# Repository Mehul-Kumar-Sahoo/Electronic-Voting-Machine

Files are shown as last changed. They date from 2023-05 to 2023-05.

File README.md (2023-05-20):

# Electronic Voting Machine (EVM)

Skills: Proteus 7, Digital Electronics

- I am Mehul Kumar Sahoo of in B.Tech Part 2 in IIT (BHU), Varanasi persuing Electronics Engineering. 
- I have made an Electronic Voting Machine (EVM) using PROTEUS for the event of DIGISIM in Udyam'23, annual technical fest of Electronics Engineering Society IIT (BHU), Varanasi.
- I have also designed a PCB using EagleCAD to implement the EVM (Schematic, Board and Gerber files are also attached in this repository).



## Features
 1) A start button to begin the voting process for a voter giving them a window of 15 seconds to vote for a person.
 
 
 
 2) After each voting button is pressed, the circuit stops working for 3 seconds to prevent devouncing of a button.



 3) A count button which when pressed counts the number of votes the winning person has.
 4) 7-segment displays to display the winning candidate, the number of votes for winning candidate, and the time left for voting.
 
 

## PCB Design (Made using EagleCAD)
### Top Layer



### Bottom Layer



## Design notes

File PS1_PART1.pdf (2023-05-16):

# DIGISIM PS-1 PART 1 EXPLANATION

Team Members:
1) Name – Mehul Kumar Sahoo
Email – mehul.kumarsahoo.ece21@itbhu.ac.in
2) Name – Vaibhav Bansal
Email – vaibhav.bansal.ece21@itbhu.ac.in Circuit Diagram:

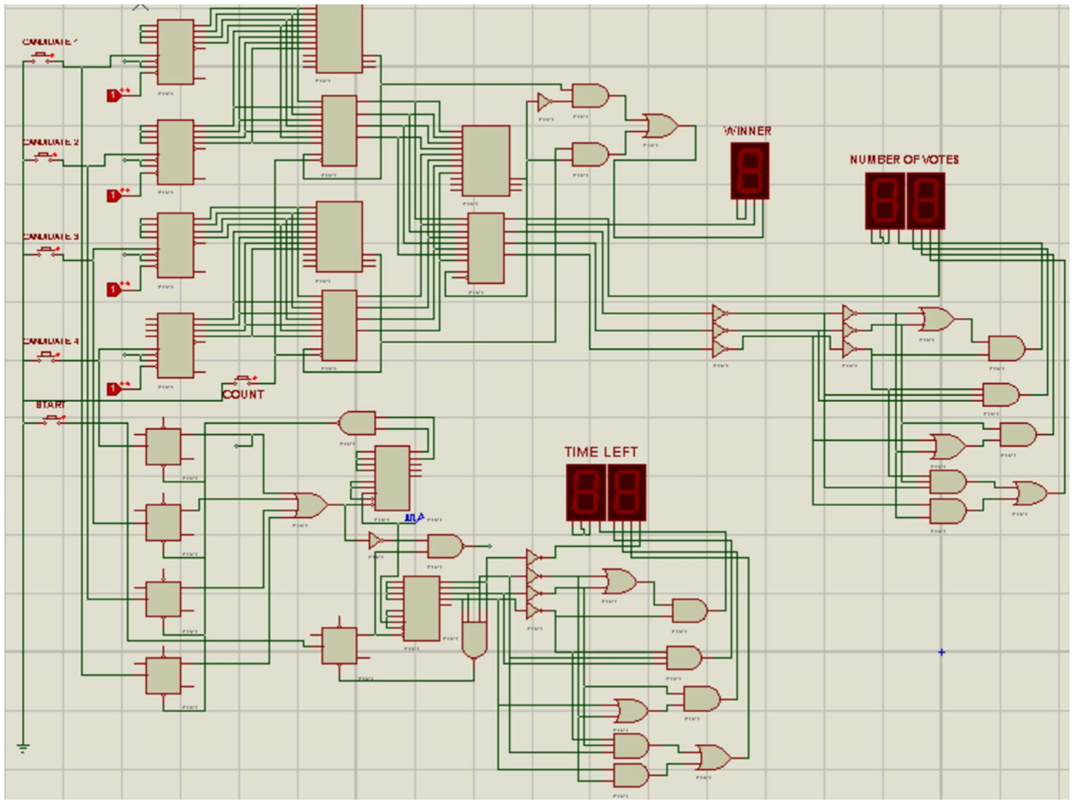
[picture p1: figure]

We have implemented the following features in the Electronic Vong Machine.

### 1. A start buon to begin the vong process gives the voter a window of 15

seconds to vote for a person.

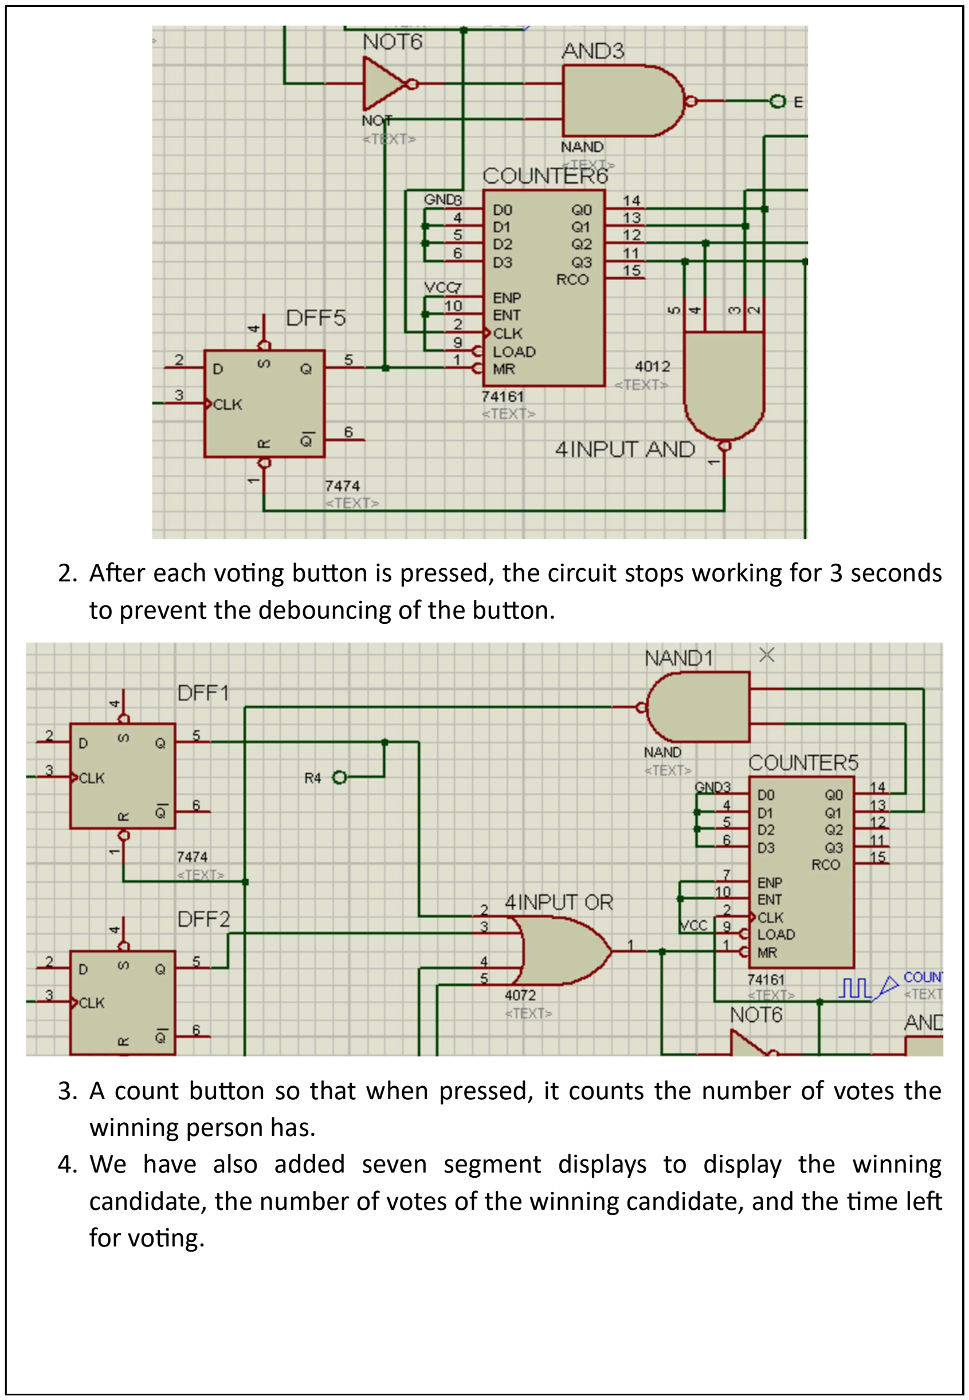
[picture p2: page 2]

### 2. Aer each vong buon is pressed, the circuit stops working for 3 seconds

to prevent the debouncing of the buon.

### 3. A count buon so that when pressed, it counts the number of votes the

winning person has.

### 4. We have also added seven segment displays to display the winning

candidate, the number of votes of the winning candidate, and the me le for vong.

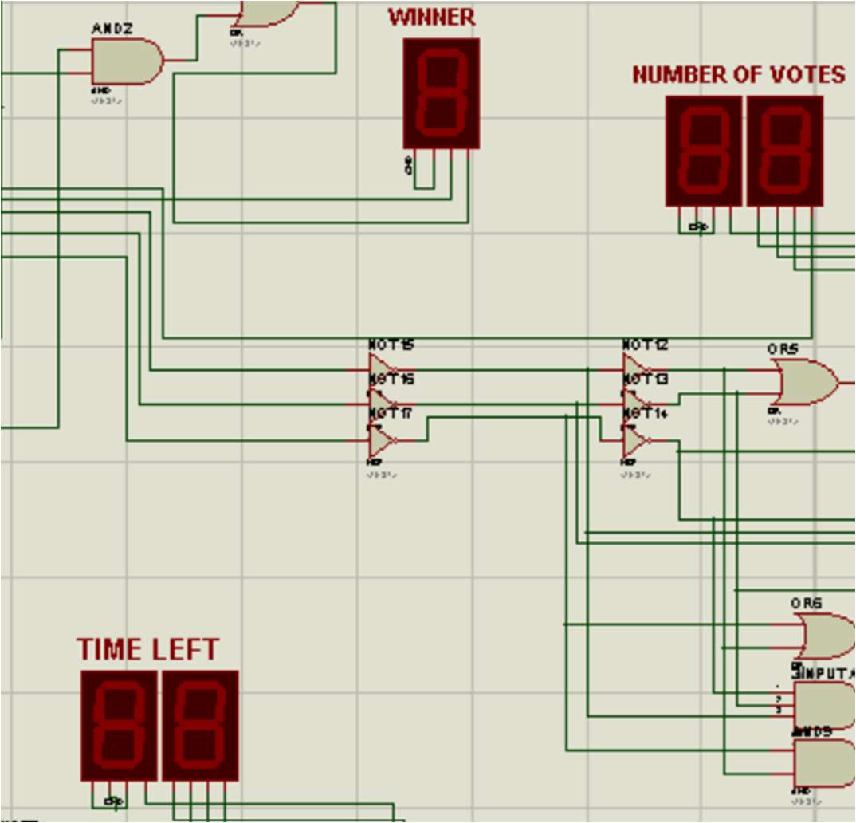
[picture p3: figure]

We have implemented all the above features in the circuit made in Proteus as well as in the PCB.
We have made a 2-layered PCB of the schemac made in PROTEUS

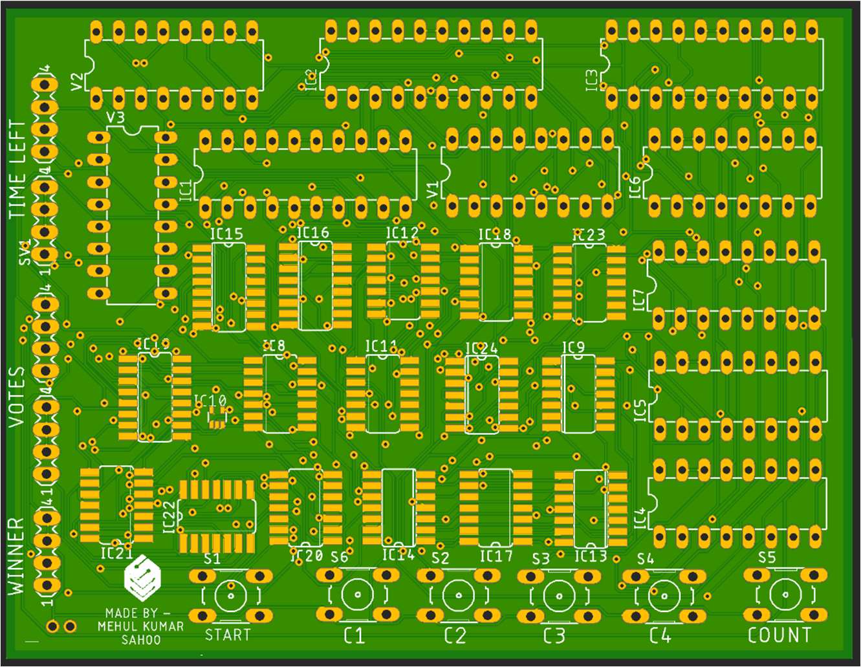
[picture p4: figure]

For most of the components, we have used SMT PCB packages, but unfortunately, for some components, only THT PCB packages were available. We have used 4 pin holes for the connecons of the 7 Segment BCD displays (Not available in EAGLE CAD). Similarly, for providing a clock cycle, we have used 2 pins at the boom right so that we can connect the funcon generator from there. All the buons are also marked according to their funcons. We have applied Copper masking on both sides of the PCB, which will act as a heat sink. We have also added an EES logo in the boom le of the PCB.

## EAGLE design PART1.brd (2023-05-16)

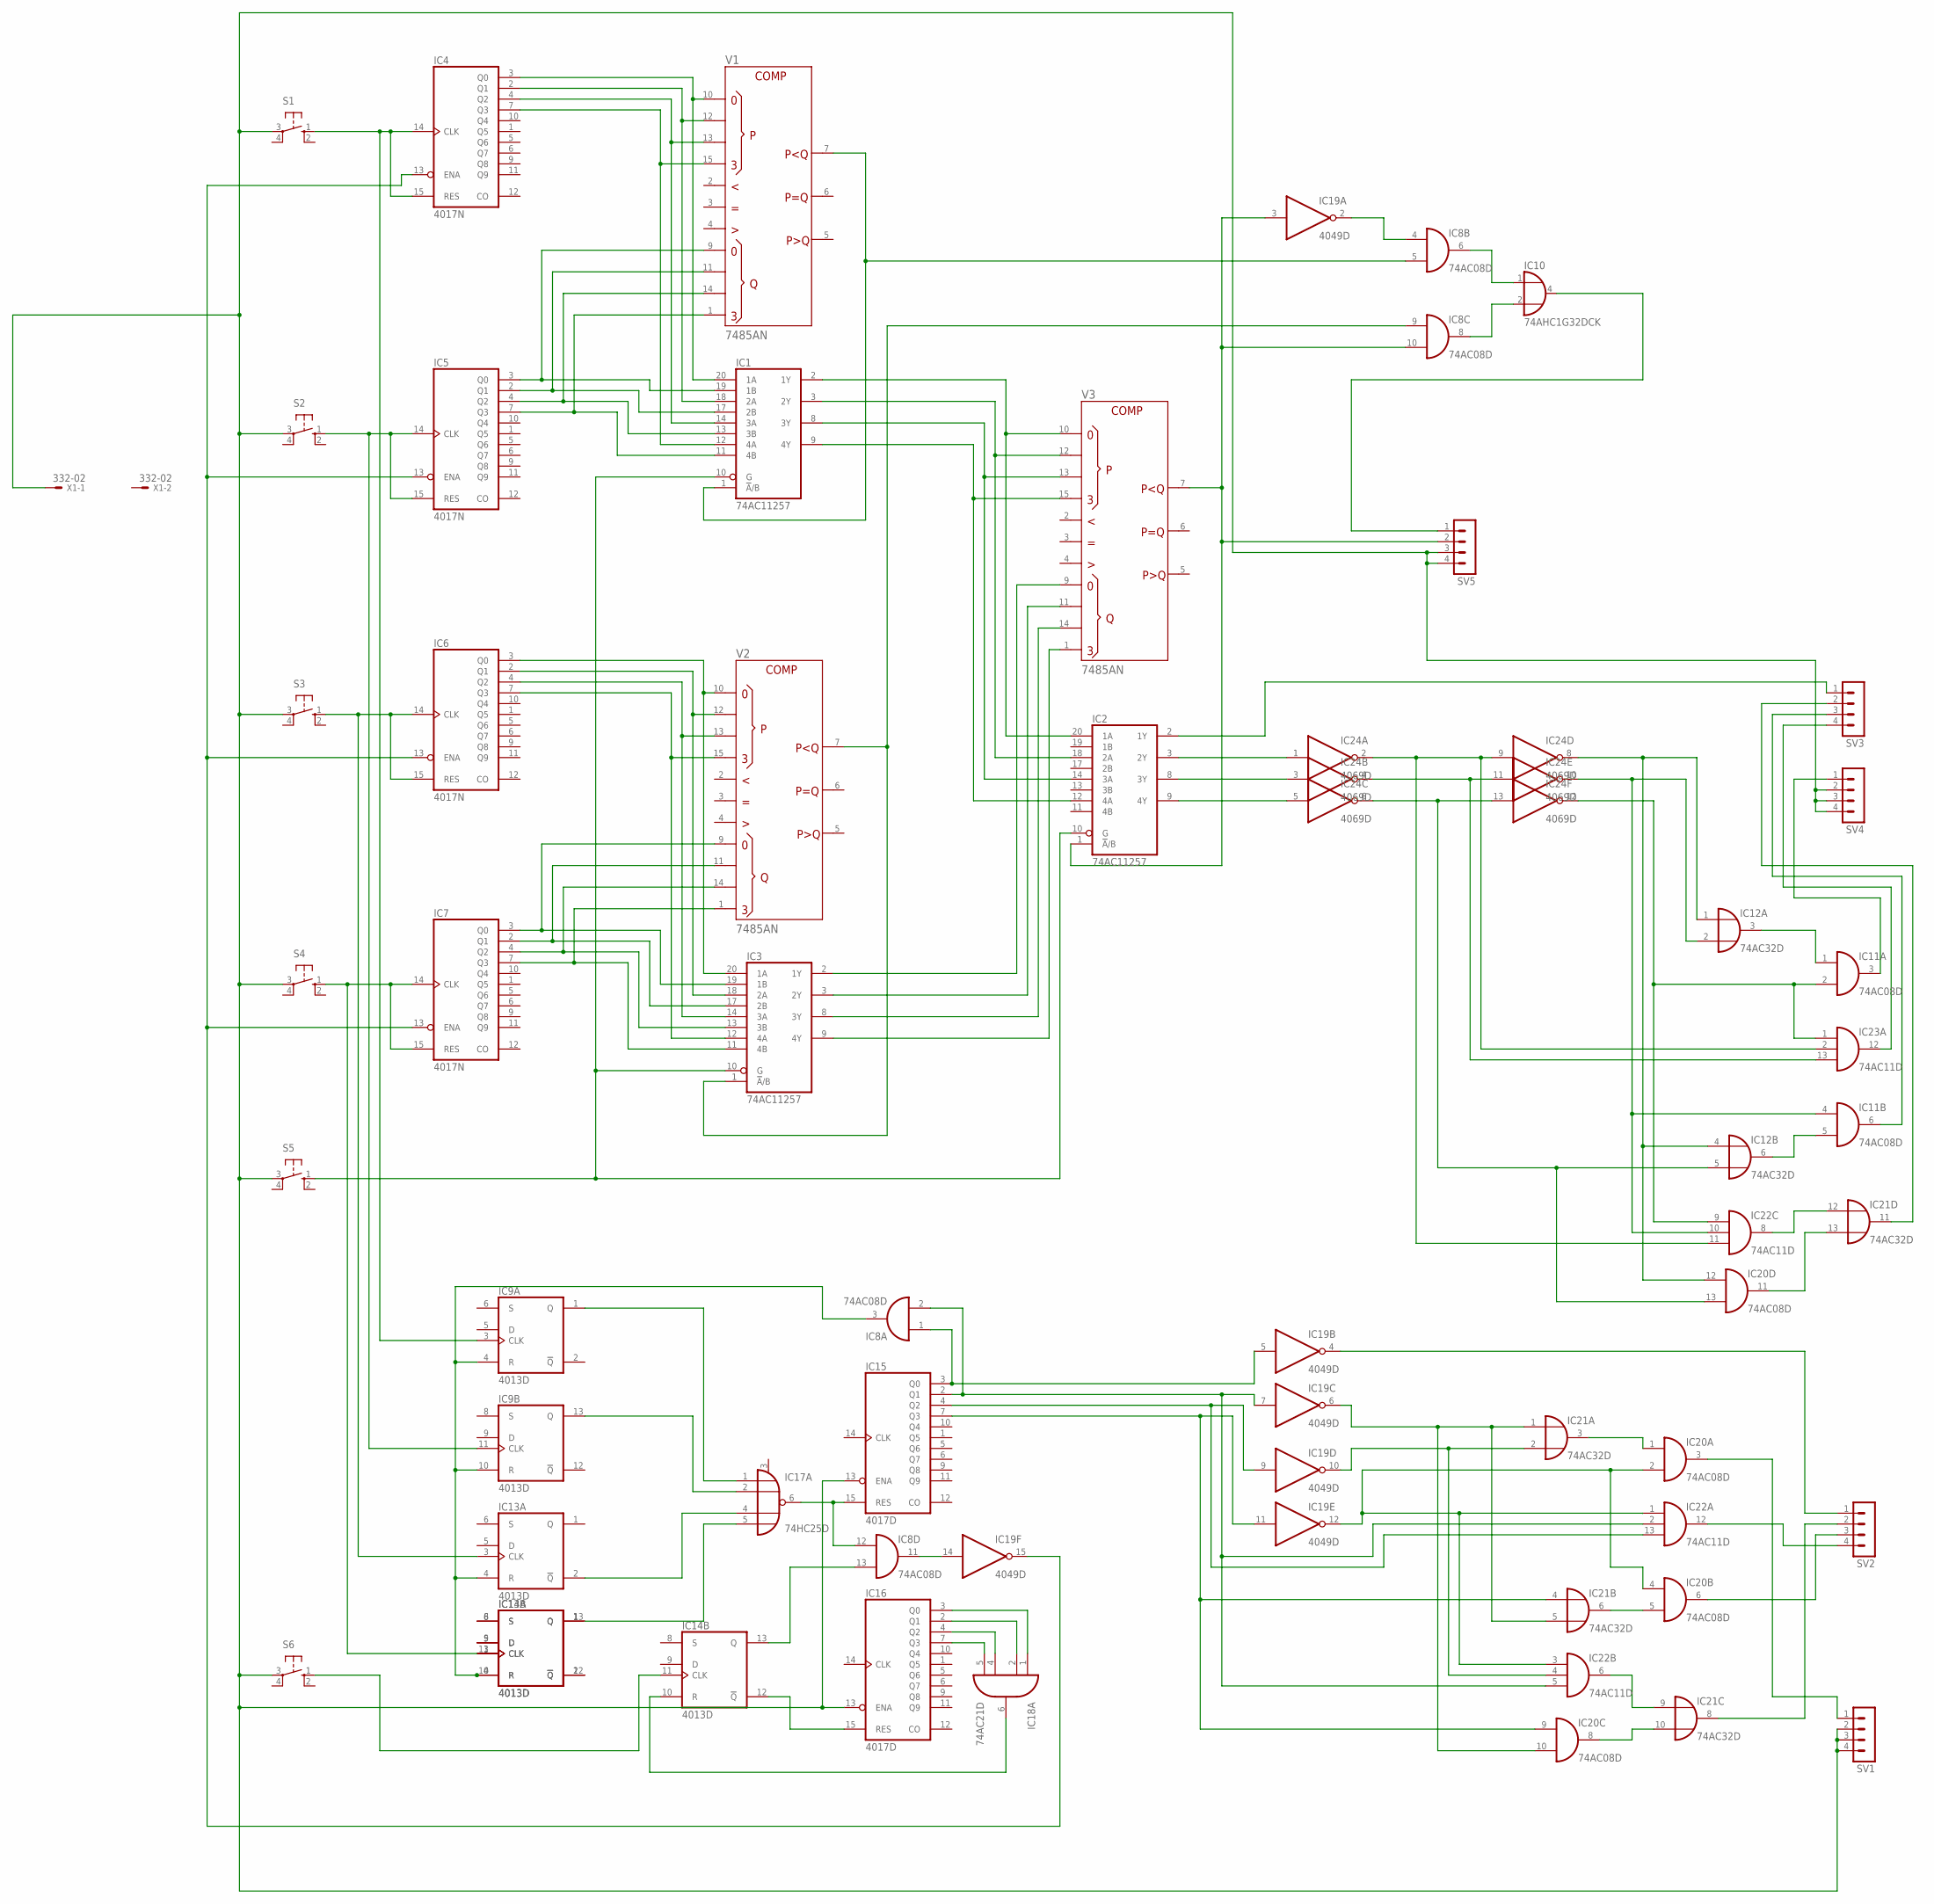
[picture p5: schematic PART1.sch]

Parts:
IC1, IC2, IC3: 74AC11257; DIL20
IC4, IC5, IC6, IC7: 4017N; DIL16
IC8, IC11, IC20: 74AC08D; SO14
IC9, IC13, IC14: 4013D; SO14
IC10: 74AHC1G32DCK; SC70-5
IC12, IC21: 74AC32D; SO14
IC15, IC16: 4017D; SO16
IC17: 74HC25D; SO14
IC18: 74AC21D; SO14
IC19: 4049D; SO16
IC22, IC23: 74AC11D; SO14
IC24: 4069D; SO14
S1, S2, S3, S4, S5, S6: 10-XX; B3F-10XX
SV1, SV2, SV3, SV4, SV5: MA04-1
V1, V2, V3: 7485AN; DIL16
X1: 332-02

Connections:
+UB: V1.16 (+UB), V2.16 (+UB), V3.16 (+UB)
-UB: V1.8 (-UB), V2.8 (-UB), V3.8 (-UB)
GND: IC1.4 (GND), IC1.5 (GND), IC1.6 (GND), IC1.7 (GND), IC2.4 (GND), IC2.5 (GND), IC2.6 (GND), IC2.7 (GND), IC3.4 (GND), IC3.5 (GND), IC3.6 (GND), IC3.7 (GND), IC8.7 (GND), IC10.3 (GND), IC11.7 (GND), IC12.7 (GND), IC17.7 (GND), IC18.7 (GND), IC20.7 (GND), IC21.7 (GND), IC22.7 (GND), IC23.7 (GND)
unnamed: IC13.2 (!Q), IC17.4 (I2)
unnamed: IC1.20 (1A), IC4.3 (Q0), V1.10 (P0)
unnamed: IC5.14 (CLK), IC5.15 (RES), IC9.11 (CLK), S2.1 (S)
unnamed: IC6.14 (CLK), IC6.15 (RES), IC13.3 (CLK), S3.1 (S)
unnamed: IC1.18 (2A), IC4.2 (Q1), V1.12 (P1)
unnamed: IC1.14 (3A), IC4.4 (Q2), V1.13 (P2)
unnamed: IC4.13 (ENA), IC5.13 (ENA), IC6.13 (ENA), IC7.13 (ENA), IC19.15 (O)
unnamed: IC1.12 (4A), IC4.7 (Q3), V1.15 (P3)
unnamed: IC1.19 (1B), IC5.3 (Q0), V1.9 (Q0)
unnamed: IC1.17 (2B), IC5.2 (Q1), V1.11 (Q1)
unnamed: IC1.13 (3B), IC5.4 (Q2), V1.14 (Q2)
unnamed: IC1.11 (4B), IC5.7 (Q3), V1.1 (Q3)
unnamed: IC3.11 (4B), IC7.7 (Q3), V2.1 (Q3)
unnamed: IC1.10 (G), IC2.10 (G), IC3.10 (G), S5.1 (S)
unnamed: IC1.2 (1Y), IC2.20 (1A), V3.10 (P0)
unnamed: IC1.3 (2Y), IC2.18 (2A), V3.12 (P1)
unnamed: IC3.20 (1A), IC6.3 (Q0), V2.10 (P0)
unnamed: IC3.18 (2A), IC6.2 (Q1), V2.12 (P1)
unnamed: IC3.14 (3A), IC6.4 (Q2), V2.13 (P2)
unnamed: IC3.12 (4A), IC6.7 (Q3), V2.15 (P3)
unnamed: IC3.19 (1B), IC7.3 (Q0), V2.9 (Q0)
unnamed: IC3.17 (2B), IC7.2 (Q1), V2.11 (Q1)
unnamed: IC3.13 (3B), IC7.4 (Q2), V2.14 (Q2)
unnamed: IC1.8 (3Y), IC2.14 (3A), V3.13 (P2)
unnamed: IC2.1 (!A!/B), IC8.10 (I1), IC19.3 (I), SV5.2, V3.7 (PLTQ)
unnamed: IC3.9 (4Y), V3.1 (Q3)
unnamed: IC3.8 (3Y), V3.14 (Q2)
unnamed: IC3.3 (2Y), V3.11 (Q1)
unnamed: IC1.1 (!A!/B), IC8.5 (I1), V1.7 (PLTQ)
unnamed: IC3.1 (!A!/B), IC8.9 (I0), V2.7 (PLTQ)
unnamed: IC3.2 (1Y), V3.9 (Q0)
unnamed: IC8.4 (I0), IC19.2 (O)
unnamed: IC8.8 (O), IC10.2 (I1)
unnamed: IC8.6 (O), IC10.1 (I0)
unnamed: IC10.4 (O), SV5.1
unnamed: IC1.9 (4Y), IC2.12 (4A), V3.15 (P3)
unnamed: IC22.11 (I2), IC23.2 (I1), IC24.2 (O), IC24.9 (I)
unnamed: IC23.13 (I2), IC24.4 (O), IC24.11 (I)
unnamed: IC12.5 (I1), IC20.13 (I1), IC24.6 (O), IC24.13 (I)
unnamed: IC12.1 (I0), IC12.4 (I0), IC20.12 (I0), IC24.8 (O)
unnamed: IC2.9 (4Y), IC24.5 (I)
unnamed: IC2.8 (3Y), IC24.3 (I)
unnamed: IC2.3 (2Y), IC24.1 (I)
unnamed: IC2.2 (1Y), SV3.1
unnamed: IC11.2 (I1), IC22.9 (I0), IC23.1 (I0), IC24.12 (O)
unnamed: IC11.1 (I0), IC12.3 (O)
unnamed: IC11.3 (O), SV4.1
unnamed: IC13.13 (Q), IC14.1 (Q)
unnamed: IC13.12 (!Q), IC14.2 (!Q)
unnamed: IC7.14 (CLK), IC7.15 (RES), IC13.11 (CLK), IC14.3 (CLK), S4.1 (S)
unnamed: IC8.3 (O), IC9.4 (R), IC9.10 (R), IC13.4 (R), IC13.10 (R), IC14.4 (R)
unnamed: IC13.9 (D), IC14.5 (D)
unnamed: IC13.8 (S), IC14.6 (S)
unnamed: IC8.1 (I0), IC15.3 (Q0), IC19.5 (I)
unnamed: IC8.2 (I1), IC15.2 (Q1), IC19.7 (I), IC22.2 (I1), IC22.5 (I2)
unnamed: IC15.13 (ENA), IC16.13 (ENA), S1.3, S2.3, S3.3, S4.3, S5.3, S6.3, SV1.2, SV1.3, SV1.4, SV4.2, SV4.3, SV4.4, SV5.3, SV5.4, X1.1
unnamed: IC9.1 (Q), IC17.1 (I0)
unnamed: IC9.13 (Q), IC17.2 (I1)
unnamed: IC8.12 (I0), IC15.15 (RES), IC17.6 (O)
unnamed: IC16.3 (Q0), IC18.1 (I0)
unnamed: IC16.2 (Q1), IC18.2 (I1)
unnamed: IC16.4 (Q2), IC18.4 (I2)
unnamed: IC16.7 (Q3), IC18.5 (I3)
unnamed: IC14.10 (R), IC18.6 (O)
unnamed: IC8.13 (I1), IC14.13 (Q)
unnamed: IC14.11 (CLK), S6.1 (S)
unnamed: IC14.12 (!Q), IC16.15 (RES)
unnamed: IC15.4 (Q2), IC19.9 (I), IC22.13 (I2)
unnamed: IC15.7 (Q3), IC19.11 (I), IC20.9 (I0), IC21.4 (I0)
unnamed: IC8.11 (O), IC19.14 (I)
unnamed: IC19.6 (O), IC20.10 (I1), IC21.1 (I0), IC21.5 (I1)
unnamed: IC4.14 (CLK), IC4.15 (RES), IC9.3 (CLK), S1.1 (S)
unnamed: IC19.10 (O), IC21.2 (I1), IC22.4 (I1)
unnamed: IC20.1 (I0), IC21.3 (O)
unnamed: IC19.12 (O), IC20.2 (I1), IC20.4 (I0), IC22.1 (I0), IC22.3 (I0)
unnamed: IC19.4 (O), SV2.1
unnamed: IC21.8 (O), SV2.2
unnamed: IC20.6 (O), SV2.3
unnamed: IC22.12 (O), SV2.4
unnamed: IC20.5 (I1), IC21.6 (O)
unnamed: IC21.9 (I0), IC22.6 (O)
unnamed: IC20.8 (O), IC21.10 (I1)
unnamed: IC20.3 (O), SV1.1
unnamed: IC23.12 (O), SV3.4
unnamed: IC11.5 (I1), IC12.6 (O)
unnamed: IC11.6 (O), SV3.3
unnamed: IC21.12 (I0), IC22.8 (O)
unnamed: IC20.11 (O), IC21.13 (I1)
unnamed: IC11.4 (I0), IC12.2 (I1), IC22.10 (I1), IC24.10 (O)
unnamed: IC21.11 (O), SV3.2
VCC: IC1.15 (VCC), IC1.16 (VCC), IC2.15 (VCC), IC2.16 (VCC), IC3.15 (VCC), IC3.16 (VCC), IC8.14 (VCC), IC10.5 (VCC), IC11.14 (VCC), IC12.14 (VCC), IC17.14 (VCC), IC18.14 (VCC), IC20.14 (VCC), IC21.14 (VCC), IC22.14 (VCC), IC23.14 (VCC)
VDD: IC4.16 (VDD), IC5.16 (VDD), IC6.16 (VDD), IC7.16 (VDD), IC9.14 (VDD), IC13.14 (VDD), IC14.14 (VDD), IC15.16 (VDD), IC16.16 (VDD), IC19.1 (VDD), IC24.14 (VDD)
VSS: IC4.8 (VSS), IC5.8 (VSS), IC6.8 (VSS), IC7.8 (VSS), IC9.7 (VSS), IC13.7 (VSS), IC14.7 (VSS), IC15.8 (VSS), IC16.8 (VSS), IC19.8 (VSS), IC24.7 (VSS)

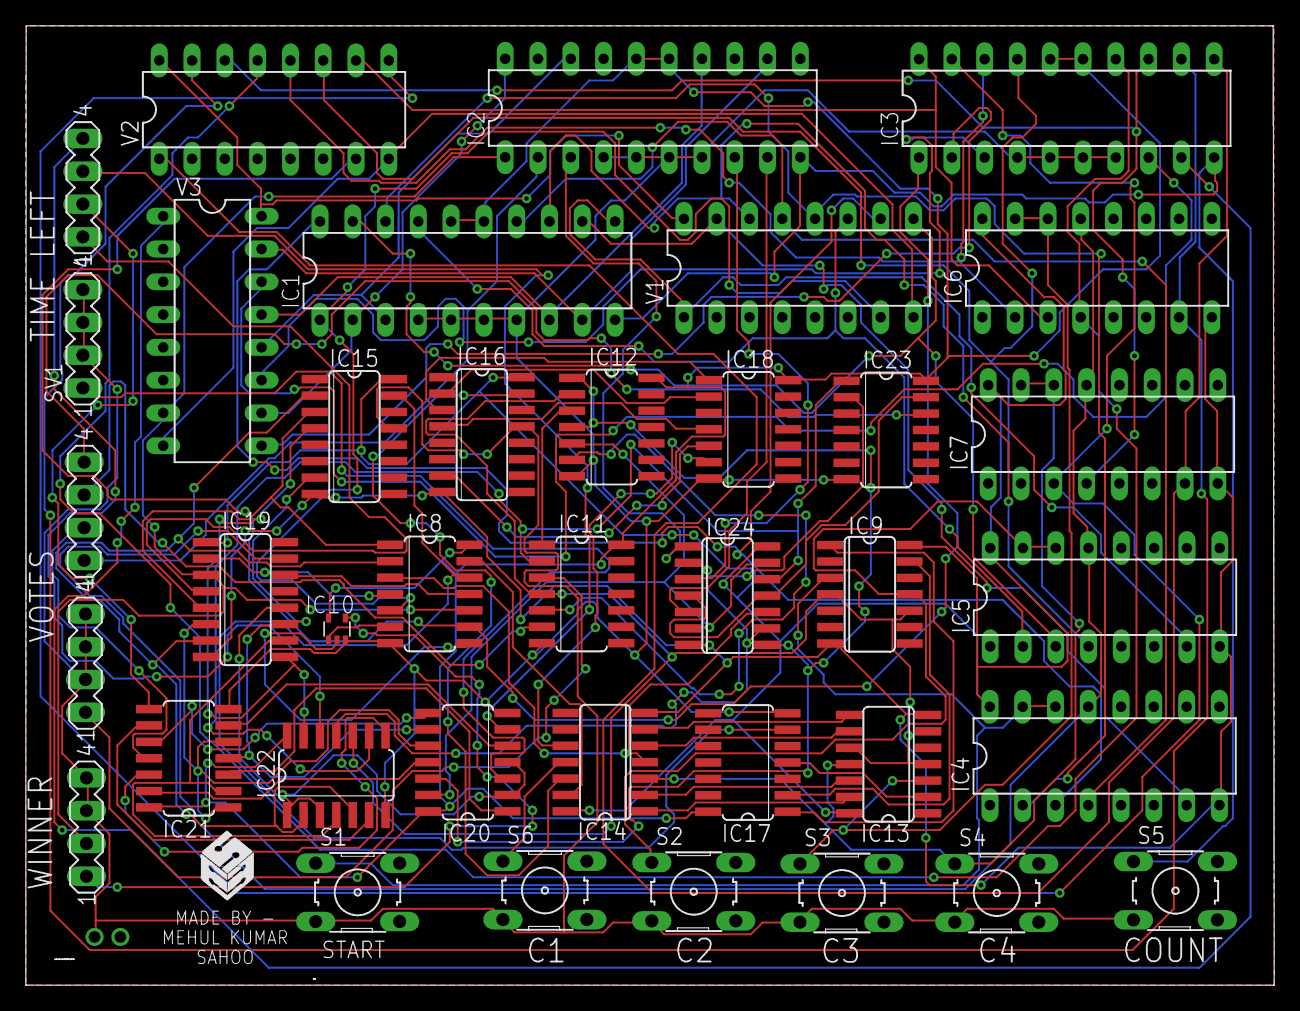
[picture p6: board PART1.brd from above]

Board: 2 copper layers, 96.7 x 74.3 mm, 39 parts (1 on the bottom side), 96 nets.
